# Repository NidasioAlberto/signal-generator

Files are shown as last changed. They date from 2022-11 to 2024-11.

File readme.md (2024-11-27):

# Signal Generator with an STM32

## Introduction

The main idea of this project is to develop a waveform generator instrument using an STM32 microcontroller and its built-in DAC. The project has 2 parts:
- **Software**: The application needs to showcase the STM32 capability to output
            waveforms  at sample rates of 100kHz or greater. The software has to include a
            peripheral driver to access the built in DAC using DMA.
- **Hardware**: The device has to to implement a waveform generator output stage
            circuitry that allows to extend the capabilities of the built in DAC.

To achieve this goals a custom board was designed and software drivers were developed for the DAC and DMA. The final product also includes a text interface where the user can setup an arbitrary waveform and the device parses the user input using Flex and Bison.

<div align="center">
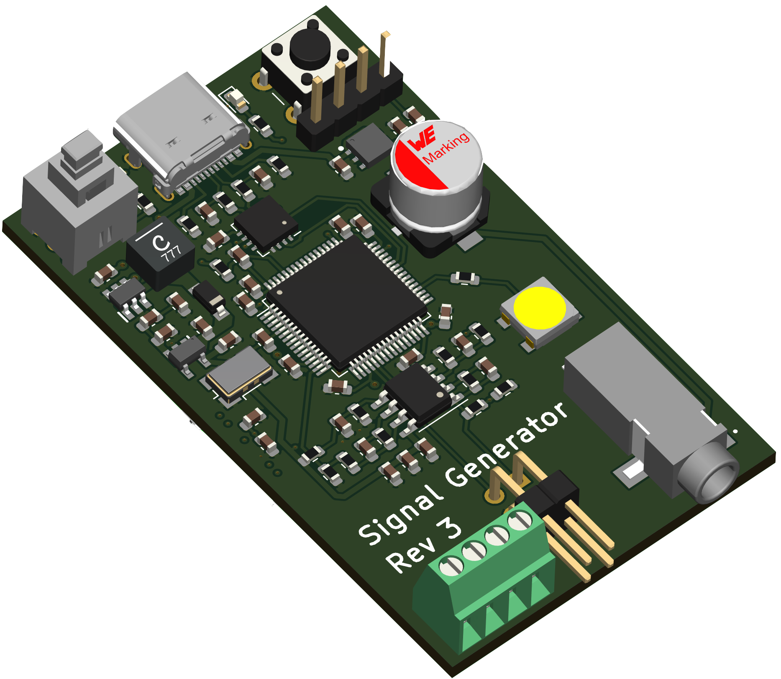
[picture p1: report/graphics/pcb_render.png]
Console Example
    
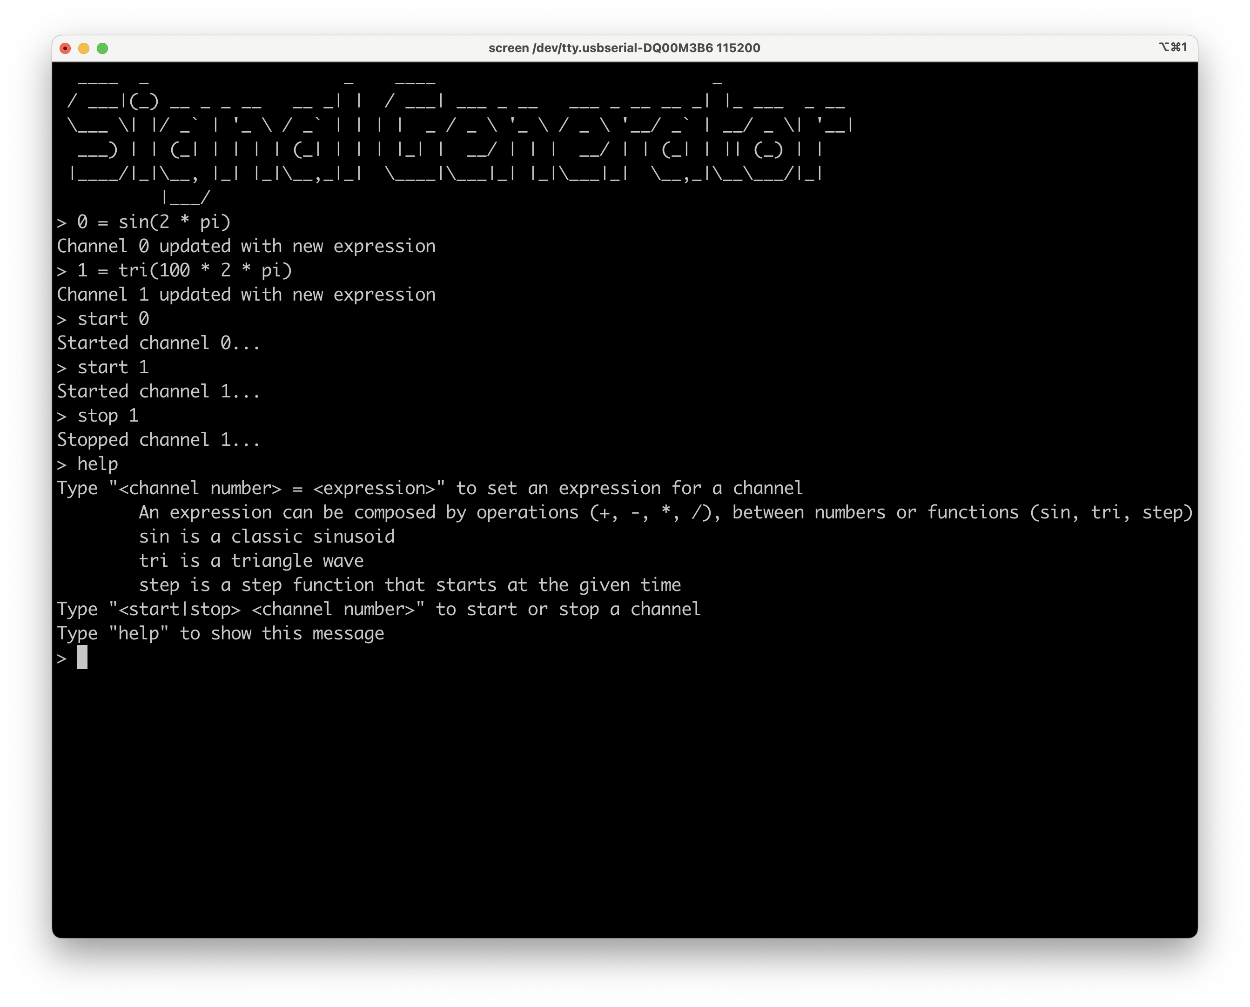
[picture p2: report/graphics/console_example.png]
PCB Render
    
</div>

## Analog Front End

The stm32 incorporates a Digital-to-Analog Converter (DAC) with an integrated output buffer. When enabled, the buffer allows the DAC to drive external loads directly. However, this comes at the cost of limited driving capability, especially when interfacing with capacitive loads. Disabling the buffer offers a pure analog output, but necessitates an external buffer or amplifier to drive any meaningful external load. The inherent impedance of the DAC's output pin can also cause distortions and constrain the signal's frequency, particularly when dealing with capacitive loads.

Integrating an external operational amplifier (op-amp) into the analog front-end offers multiple advantages:

- **Buffering DAC Output**: The op-amp serves as a buffer, isolating the DAC from the actual load. This setup minimizes the effects of the DAC output pin's impedance, enabling the DAC to operate in a near-ideal environment.
- **Voltage Scaling**: Configured in a non-inverting amplifier mode, the op-amp provides adjustable gain, facilitating flexible signal amplitude adjustments.

Given that the board is powered via USB, which typically provides 5V, there's a need to step up this voltage to achieve the 12V requirement for the analog front end:

- **Boost Converter**: The TLV61048 boost converter is employed to step up the USB's 5V to 13.12V.
- **Linear Voltage Regulator**: Following the boost converter, an LDO is used to convert the 13.12V from the boost converter to a stable 12V output. This stable 12V supply is crucial to ensure that the analog front-end, especially the operational amplifier, operates with consistency.

The opamp circuit also features a voltage divider to feedback the output signal to the STM32's ADC. This could allow the microcontroller to perform automatic calibration of the opamp gains.
Here's the provided LaTeX content converted into markdown:

## Microcontroller and digital domain

The STM32F205 is a low-end microcontroller with a 120MHz clock speed, 128KB of RAM, and the required peripherals needed by the project (DAC, DMA, and timers). It was used mainly because it was already stocked in the lab.

The board also features:
- An external 25MHz crystal oscillator to drive the microcontroller.
- A USB to UART bridge to allow the user to interact with the device via a serial terminal.
- An RGBW addressable led used for status indication.
- A header connector that exposes the SWD programming interface.
- Two buttons: one for reset and one for the BOOT0 pin.
- A microSD card slot to store files.

## Software architecture

The software powering the signal generator board is built upon the [Miosix operating system](https://github.com/NidasioAlberto/miosix-kernel) and features 2 main components:
- Drivers for the DAC and DMA peripherals.
- A parser built using Flex and Bison that allows interpreting the user input into arbitrary math functions used to generate the output waveform.

### Peripherals drivers

The STM32F205 microcontroller is equipped with a versatile Digital-to-Analog Converter (DAC) peripheral that offers 12-bit resolution and two separate channels, effectively incorporating two DACs. This dual-channel architecture permits simultaneous generation of two distinct analog outputs, allowing our custom board to feature two independent output channels.

The DAC's conversion process can be initiated through multiple methods. It can be triggered manually via software, which provides direct control over the conversion timing. Alternatively, for applications requiring precise and periodic analog outputs, external triggers can be employed. A common external trigger source is a timer, which can initiate DAC conversions at predetermined intervals, ensuring consistent waveform generation.

The STM32's DAC is also designed with the capability to generate DMA requests. Once the DAC is ready for new data, it can signal the DMA peripheral to fetch the next data sample. The DMA (Direct Memory Access) controller is a powerful tool designed to handle data transfers independently of the CPU's operation. This peripheral is characterized by sixteen independent streams, each of which can be paired with different peripherals, granting a wide range of configuration possibilities. By leveraging the DMA's rapid data transfer capabilities, the DAC can be persistently supplied with data while leaving the CPU time to generate new data samples or perform other tasks.

One of its standout features is the double buffering mode. This mode uses two memory pointers: while one buffer is actively engaged by the DMA stream, the other can be prepared by the CPU, ensuring uninterrupted data flow.

In the context of the signal generator project, the DMA plays a crucial role. Each DAC is set up to utilize an external trigger originating from a timer. With every trigger event, the DAC issues a DMA request for a new data sample. The DMA has been configured in double buffer mode. Alternatively, a single buffer mode combined with the half-transfer interrupt could have been adopted to achieve a similar result. This integration of the DAC with the DMA and a timer is what ultimately powers the project's ability to generate high-frequency waveforms even with a low-end microcontroller such as the STM32F205.

The developed drivers are C++ classes that abstract the peripherals and allow the programmer to easily configure and use them. In particular, the DMA driver is divided into two classes and one struct:
- **DMADriver**: A singleton that manages all DMA streams. When a piece of code needs a stream, it can request it to the DMADriver. If the stream is already in use, the DMADriver will pause the thread until the stream is available, otherwise, it will acquire the stream and return it to the caller.
- **DMATransaction**: A struct that holds all configuration parameters for a specific transfer. This includes source and destination addresses, data size, double buffer, interrupts, and so on.
- **DMAStream**: This class allows configuring the stream for a specific transaction, start and stop it, and easily handle interrupts. In particular, interrupts can be waited for with or without a timeout (thanks to the Miosix's timed wait feature) or registering a callback function that will be called when the interrupt occurs.

# Project outcomes

## Concrete outcomes

The project achieved two concrete outcomes:
- **Electronic board**: The board was designed and assembled successfully. It includes an analog front end that extends the capabilities of the STM32's built-in DAC and also includes features, such as the ADC feedback and micro SD, that allows further experimentation.
- **Software drivers**: Two software drivers were developed, one for the DAC and one for the DMA. These allow the use of the peripherals in a simple and efficient way.

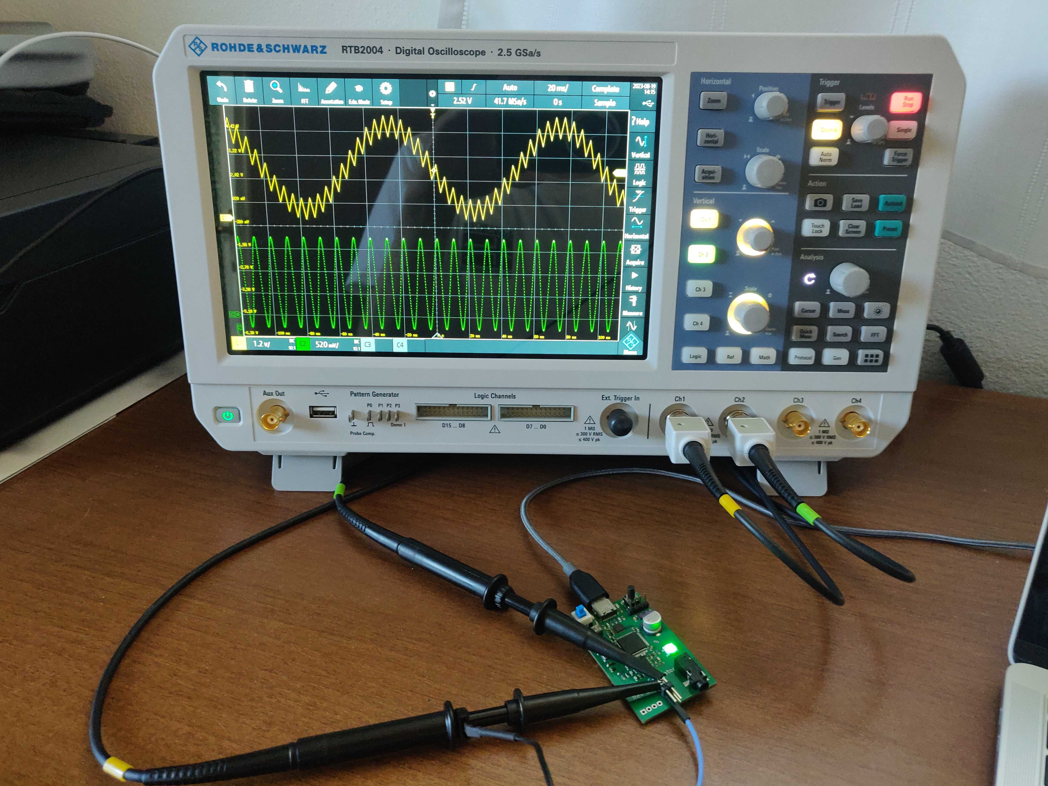
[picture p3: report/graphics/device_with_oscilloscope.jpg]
Signal Generator board hooked up to an oscilloscope


## Learning outcomes

Developing both the hardware and the software allowed me not only to learn about the STM32 microcontroller and its peripherals but also to learn about the whole process of designing and assembling a PCB.

Particular effort went into the design of the board itself, selecting and sourcing the components, and manually assembling the board. It was a challenge because, being my first time creating a complex PCB with a microcontroller, I was not well prepared. I had to learn about the different types of components, which were required for my design, and which not. Some special takeaways were the importance of reading carefully the components datasheet, finding application notes to understand similar projects, and learning how to design and order a PCB (with KiCad and JLCPCB).

The assembly of the board was the most exciting part because I got to see my design come to life. I procured the necessary soldering equipment (solder paste, a hot plate, a hot air gun, and a microscope) and I soldered the board first by distributing the solder paste with a stencil and then by heating the board with the hot plate for the top layer, and with the hot air gun for the bottom layer. I had to learn how to use the equipment and how to solder the different components.

The software side was instead more akin to my previous experiences. I had already worked with microcontrollers and already used the Miosix operating system. However, I had never worked with the DMA peripheral. The most challenging aspects were understanding how the peripherals work by reading the reference manual and also finding examples online which are hard to come by.

## Existing knowledge

The most useful knowledge that helped me in this project came from 3 sources:
- **Advanced Operating System**: In particular, the parts on concurrency, thread programming, and analysis of the features in the Miosix operating system.
- **Embedded Systems**: The course gave me a good understanding of the development process of a microcontroller-based system, both for the design aspects and for the production processes involved.
- **Skyward Experimental Rocketry**: Most of the experience I had prior to this academic year was my involvement in the Skyward Experimental Rocketry team. Previously I was involved in the design and development of the software for the rocket. This year I also had the responsibility of managing the production of the avionic system as a whole, including the electronic part. This gave me a good opportunity to work on another project and the luck of knowing lots of talented teammates.

## Problems encountered

The worst setback I faced was the board redesign. In the first version, I used an STM32F103 which is a cheaper microcontroller that has no built-in DAC! I realized this only after I had assembled the board and tried to use it. I had to adjust the schematic and the PCB in order to use the STM32F205 instead and reorder the board.

Once the board was ready I faced other problems during the development of the drivers but I managed to solve them without major issues. In this process, the debugger was particularly useful to understand what was going on.

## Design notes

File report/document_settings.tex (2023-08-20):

\usepackage[english]{babel}
\usepackage[utf8x]{inputenc}
\usepackage{amsmath}
\usepackage{graphicx}
\usepackage[colorinlistoftodos]{todonotes}
\usepackage{hyperref}
\usepackage[a4paper]{geometry}
\geometry{top=3cm,left=2cm,right=2cm,bottom=3cm}
\usepackage[scaled]{helvet}
\usepackage[T1]{fontenc}
\renewcommand\familydefault{\sfdefault}
\usepackage{caption}
\usepackage{subcaption}

\hypersetup{
    colorlinks=true,
    linkcolor=black,
    filecolor=blue,
    urlcolor=magenta,
    citecolor=black,
}

\setlength{\parindent}{0pt}

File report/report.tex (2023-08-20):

\documentclass{article}

\input{document_settings.tex}

\author{Alberto Nidasio}
\date{\today}
\title{Signal Generator with an STM32}

\begin{document}

\maketitle
\tableofcontents

% \let\clearpage\relaxs
\input{sections/1_project_data.tex}
\input{sections/2_project_description.tex}
\input{sections/3_project_outcomes.tex}
\input{sections/4_honor_pledges.tex}

\end{document}

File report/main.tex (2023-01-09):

\documentclass{article}

\input{document_settings.tex}

\author{Alberto Nidasio}
\date{\today}
\title{Signal Generator with an STM32}

\begin{document}

\maketitle
\tableofcontents

\include{sections/project_data.tex}
\include{sections/project_description.tex}
\include{sections/project_outcomes.tex}
\include{sections/honor_pledges.tex}

\end{document}

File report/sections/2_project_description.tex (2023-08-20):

\section{Project description}

\subsection{Introduction}

The main idea of this project is to develop a waveform generator instrument using an STM32 microcontroller and its built-in DAC. The project has 2 parts:
\begin{itemize}
      \item \textbf{Software}: The application needs to showcase the STM32 capability to output
            waveforms  at sample rates of 100kHz or greater. The software has to include a
            peripheral driver to access the built in DAC using DMA.
      \item \textbf{Hardware}: The device has to to implement a waveform generator output stage
            circuitry that allows to extend the capabilities of the built in DAC.
\end{itemize}

To achieve this goals a custom board was designed and software drivers were developed for the DAC and DMA.

The final product also includes a text interface where the user can setup an arbitrary waveform and the device parses the user input using Flex and Bison.

\begin{figure}[h]
      \captionsetup[subfigure]{labelformat=empty}
      \centering
      \begin{subfigure}[b]{0.45\textwidth}
            \centering
            
            \caption{PCB}
      \end{subfigure}
      \hfill
      \begin{subfigure}[b]{0.50\textwidth}
            \centering
            
            \caption{Text interface}
      \end{subfigure}
\end{figure}

\subsection{Design of the Printed Circuit Board}

The goal I set out to achieve is create a stand-alone PCB with builtin micro controller and front-end circuit that blends the stm32's built-in features and external components, to produce a high-frequency arbitrary waveforms with a 12V peak without external power supplies.

\subsubsection{Analog Front End}

The stm32 incorporates a Digital-to-Analog Converter (DAC) with an integrated output buffer. When enabled, the buffer allows the DAC to drive external loads directly. However, this comes at the cost of limited driving capability, especially when interfacing with capacitive loads. Disabling the buffer offers a pure analog output, but necessitates an external buffer or amplifier to drive any meaningful external load. The inherent impedance of the DAC's output pin can also cause distortions and constrain the signal's frequency, particularly when dealing with capacitive loads.

\bigbreak

Integrating an external operational amplifier (op-amp) into the analog front-end offers multiple advantages:
\begin{itemize}
      \item  \textbf{Buffering DAC Output}: The op-amp serves as a buffer, isolating the DAC from the actual load. This setup minimizes the effects of the DAC output pin's impedance, enabling the DAC to operate in a near-ideal environment.
      \item \textbf{Voltage Scaling}: Configured in a non-inverting amplifier mode, the op-amp provides adjustable gain, facilitating flexible signal amplitude adjustments.
\end{itemize}

Given that the board is powered via USB, which typically provides 5V, there's a need to step up this voltage to achieve the 12V requirement for the analog front end:
\begin{itemize}
      \item \textbf{Boost Converter}: The TLV61048 boost converter is employed to step up the USB's 5V to 13.12V.
      \item \textbf{Linear Voltage Regulator}: Following the boost converter, an LDO is used to convert the 13.12V from the boost converter to a stable 12V output. This stable 12V supply is crucial to ensure that the analog front-end, especially the operational amplifier, operates with consistency.
\end{itemize}

The opamp circuit also features a voltage divider to feedback the output signal to the STM32's ADC. This could allow the microcontroller to perform automatic calibration of the opamp gains.

\begin{figure}[h]
      \captionsetup[subfigure]{labelformat=empty}
      \centering
      \begin{subfigure}[b]{0.4\textwidth}
            \centering
            
            \caption{Front end}
      \end{subfigure}
      \hfill
      \begin{subfigure}[b]{0.59\textwidth}
            \centering
            
            \caption{Power stage}
      \end{subfigure}
\end{figure}

\subsubsection{Microcontroller and digital domain}

The STM32F205 is a low-end microcontroller with a 120MHz clock speed, 128KB of RAM and the required peripherals needed by the project (DAC, DMA and timers). It was used mainly because it was already stocked in the lab.

The board also features:
\begin{itemize}
      \item An external 25MHz crystal oscillator to drive the microcontroller.
      \item A USB to UART bridge to allow the user to interact with the device via a serial terminal.
      \item An RGBW addressable led used for status indication.
      \item An header connector that exposes the SWD programming interface.
      \item Two buttons: one for reset and one for the BOOT0 pin.
      \item A microsd card slot to store files.
\end{itemize}

\subsection{Software architecture}

The software powering the signal generator board is built upon the \href{https://github.com/NidasioAlberto/miosix-kernel}{Miosix operating system} and features 2 main components:
\begin{itemize}
      \item Drivers for the DAC and DMA peripherals.
      \item A parser built using Flex and Bison that allows to interpret the user input into arbitrary math functions used to generate the output waveform.
\end{itemize}

\subsubsection{Peripherals drivers}

The STM32F205 microcontroller is equipped with a versatile Digital-to-Analog Converter (DAC) peripheral that offers 12-bit resolution and two separate channels, effectively incorporating two DACs. This dual-channel architecture permits simultaneous generation of two distinct analog outputs, allowing our custom board to feature two independent output channels.

\bigbreak

The DAC's conversion process can be initiated through multiple methods. It can be triggered manually via software, which provides direct control over the conversion timing. Alternatively, for applications requiring precise and periodic analog outputs, external triggers can be employed. A common external trigger source is a timer, which can initiate DAC conversions at predetermined intervals, ensuring consistent waveform generation.

\bigbreak

The STM32's DAC is designed also with the capability to generate DMA requests. Once the DAC is ready for new data, it can signal the DMA peripheral to fetch the next data sample. The DMA (Direct Memory Access) controller is a powerful tool designed to handle data transfers independently of the CPU's operation. This peripheral is characterized by sixteen independent streams each of which can be paired with different peripherals, granting a wide range of configuration possibilities. By leveraging the DMA's rapid data transfer capabilities, the DAC can be persistently supplied with data while leaving the CPU time to generate new data samples or perform other tasks.

One of its standout features is the double buffering mode. This mode uses two memory pointers: while one buffer is actively engaged by the DMA stream, the other can be prepared by the CPU, ensuring uninterrupted data flow.

\bigbreak

In the context of the signal generator project, the DMA plays a crucial role. Each DAC is set up to utilize an external trigger originating from a timer. With every trigger event, the DAC issues a DMA request for a new data sample. The DMA has been configured in double buffer mode. Alternatively, a single buffer mode combined with the half-transfer interrupt could have been adopted to achieve a similar result. This integration of the DAC with the DMA and a timer is what ultimately powers the project's ability to generate high-frequency waveforms even with a low end microcontroller such as the STM32F205.

\bigbreak

The developed drivers are C++ classes that abstract the peripherals and allows the programmer to easily configure and use them. In particular the DMA driver is divided into two classes and one struct:
\begin{itemize}
      \item \textbf{DMADriver}: A singleton that manages all DMA streams. When a piece of code needs a stream, it can request it to the DMADriver. If the stream is already in use, the DMADriver will pause the thread until the stream is available, otherwise it will acquire the stream and return it to the caller.
      \item \textbf{DMATransaction}: A struct that holds all configuration parameters for a specific transfer. This includes source and destination addresses, data size, double buffer, interrupts and so on.
      \item \textbf{DMAStream}: This class allows to configure the stream with for a specific transaction, start and stop it and easily handle interrupts. In particular interrupts can be waited with or without a timeout (thank to the Miosix's timed wait feature) or registering a callback function that will be called when the interrupt occurs.
\end{itemize}

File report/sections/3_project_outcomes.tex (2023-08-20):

\section{Project outcomes}

\subsection{Concrete outcomes}

The project achieved two concrete outcomes:
\begin{itemize}
      \item \textbf{Electronic board}: The board was designed and assembled successfully. It includes an analog front end that extends the capabilities of the STM32's built in DAC and also includes features, such as the adc feedback and micro sd, that allows further experimentation.
      \item \textbf{Software drivers}: Two software drivers were developed, one for the DAC and one for the DMA. These allows to use the peripherals in a simple and efficient way.
\end{itemize}

\begin{figure}[h]
      \captionsetup[figure]{labelformat=empty}
      \centering
      
      \caption{Signal Generator board hooked up to an oscilloscope}
\end{figure}

\subsection{Learning outcomes}

Developing both the hardware and the software allowed me not only to learn about the stm32 microcontroller and its peripherals, but also to learn about the whole process of designing and assembling a PCB.

\bigbreak

Particular effort went into the design of the board itself, selecting and sourcing the components and manually assembling the board. It was a challenge because, being my first time creating a complex PCB with a microcontroller, I was not well prepared. I had to learn about the different types of components, which were required for my design and which not. Some special takeaways were the importance of reading carefully the components datasheet, finding application notes to understand similar projects and learning how to design and order a PCB (with KiCad and JLCPCB).

\bigbreak

The assembly of the board was the most exciting part because I got to see my design come to life. I procured the necessary soldering equipment (solder paste, a hot plate, a hot air gun and a microscope) and I soldered the board first by distributing the solder paste with a stencil and then by heating the board with the hot plate for the top layer, and with the hot air gun for the bottom layer. I had to learn how to use the equipment and how to solder the different components.

\bigbreak

The software side was instead more akin to my previous experiences. I had already worked with microcontrollers and already used the Miosix operating system. However, I had never worked with the DMA peripheral. The most challenging aspects were to understand how the peripherals works by reading the reference manual and also find examples online which are hard to come by.

\subsection{Existing knowledge}

The most useful knowledge that helped me in this project came from 3 sources:
\begin{itemize}
      \item \textbf{Advanced Operating System}: In particular the parts on concurrency, thread programming and analysis of the features in the Miosix operating system.
      \item \textbf{Embedded Systems}: The course gave me a good understanding of the development process of a microcontroller based system, both for the design aspects and for the production processes involved.
      \item \textbf{Skyward Experimental Rocketry}: Most of the experience I had prior to this academic year was my involvement in the Skyward Experimental Rocketry team. Previously I was involved in the design and development of the software for the rocket. This year I also had the responsibility of managing the production of the avionic system as a whole, including the electronic part. This gave me a good opportunity to work on another project and the luck of knowing lots of talented teammates.
\end{itemize}

\subsection{Problems encountered}

The worst setback I faced was the board redesign. In the first version I used an STM32F103 which is a cheaper microcontroller that has not built in DAC! I realized this only after I had assembled the board and tried to use it. I had to adjust the schematic and the PCB in order to use the STM32F205 instead and reorder the board.

Once the board was ready I faced other problems during the development of the drivers but I managed to solve them without major issues. In this process the debugger was particularly useful to understand what was going on.

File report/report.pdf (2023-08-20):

## Signal Generator with an STM32

Alberto Nidasio

August 20, 2023

## Contents

1 Project data | 1
2 Project description | 1
3 Project outcomes | 4
4 Honor Pledge | 6

## 1 Project data

- Project supervisor: Daniele Cattaneo (daniele.cattaneo@polimi.it)
- Project author:
Last and first name | Person code | Email address
Nidasio Alberto | 10665344 | alberto.nidasio@mail.polimi.com
- The project available on GitHub in this repository. (https://github.com/NidasioAlberto/signal-generator) It contains:
Folder | Content
code | The application code
code/libs/miosix-kernel | A submodule linking to a Miosix Kernel fork (https://github.com/NidasioAlberto/miosix-kernel)
docs | Documents used for reference during development
pcb | KiCad design files of the PCB
report | LaTeX files of this report

## 2 Project description

### 2.1 Introduction

The main idea of this project is to develop a waveform generator instrument using an STM32 microcontroller and its built-in DAC. The project has 2 parts:

- Software: The application needs to showcase the STM32 capability to output waveforms at sample rates of 100kHz or greater. The software has to include a peripheral driver to access the built in DAC using DMA.
- Hardware: The device has to to implement a waveform generator output stage circuitry that allows to extend the capabilities of the built in DAC.

To achieve this goals a custom board was designed and software drivers were developed for the DAC and DMA. The final product also includes a text interface where the user can setup an arbitrary waveform and the device parses the user input using Flex and Bison.

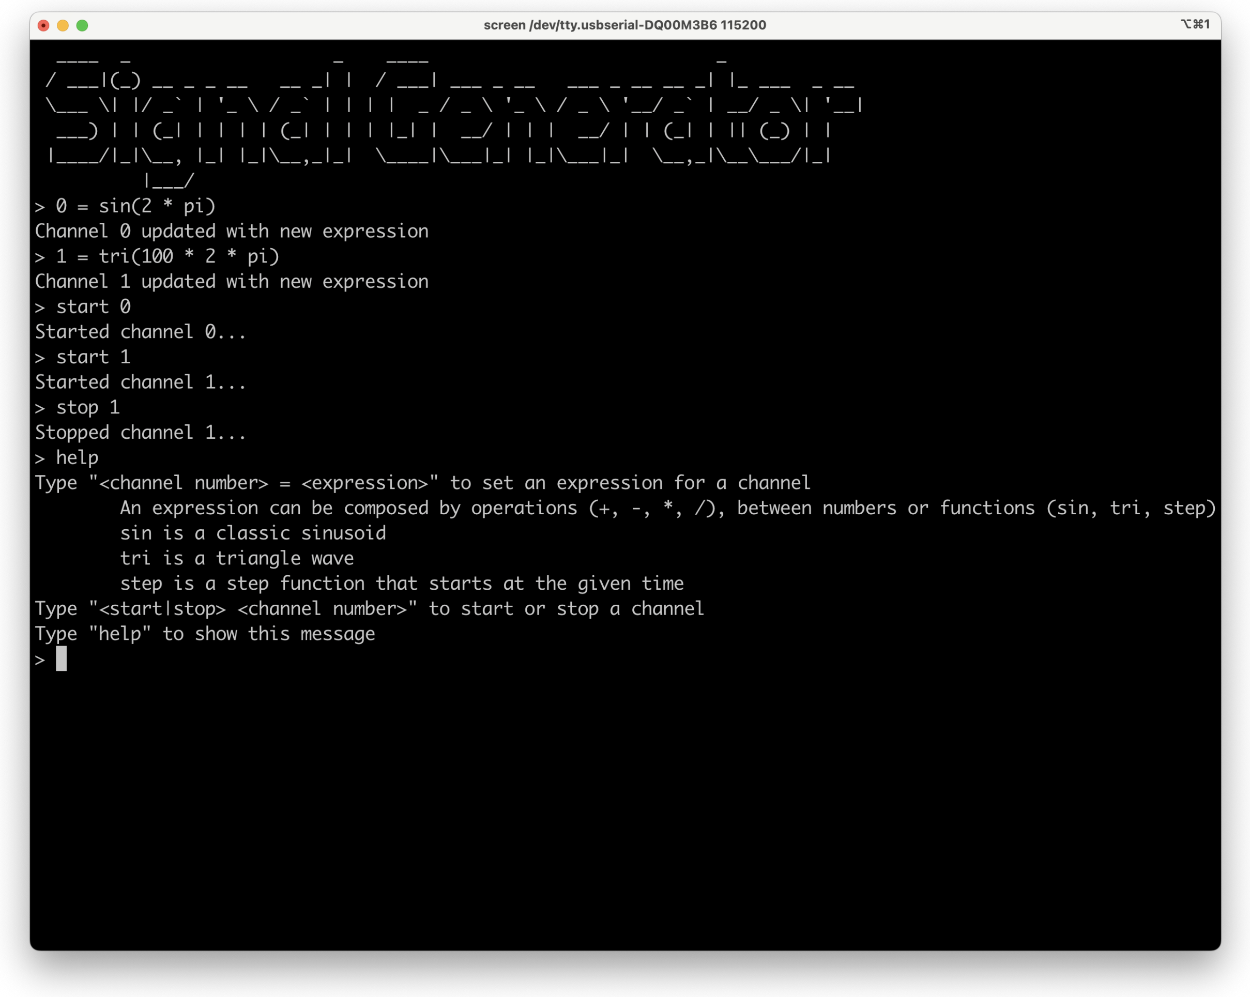
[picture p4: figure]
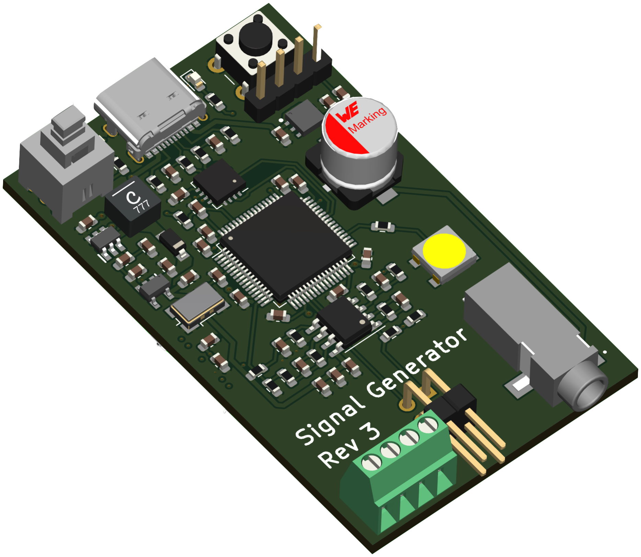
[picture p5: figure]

PCB | Text interface

### 2.2 Design of the Printed Circuit Board

The goal I set out to achieve is create a stand-alone PCB with builtin micro controller and front-end circuit that blends the stm32’s built-in features and external components, to produce a high-frequency arbitrary waveforms with a 12V peak without external power supplies.

### 2.2.1 Analog Front End

The stm32 incorporates a Digital-to-Analog Converter (DAC) with an integrated output buffer. When enabled, the buffer allows the DAC to drive external loads directly. However, this comes at the cost of limited driving capability, especially when interfacing with capacitive loads. Disabling the buffer offers a pure analog output, but necessitates an external buffer or amplifier to drive any meaningful external load. The inherent impedance of the DAC’s output pin can also cause distortions and constrain the signal’s frequency, particularly when dealing with capacitive loads.

Integrating an external operational amplifier (op-amp) into the analog front-end offers multiple advantages:

- Buffering DAC Output: The op-amp serves as a buffer, isolating the DAC from the actual load. This setup minimizes the effects of the DAC output pin’s impedance, enabling the DAC to operate in a near-ideal environment.
- Voltage Scaling: Configured in a non-inverting amplifier mode, the op-amp provides adjustable gain, facilitating flexible signal amplitude adjustments.

Given that the board is powered via USB, which typically provides 5V, there’s a need to step up this voltage to achieve the 12V requirement for the analog front end:

- Boost Converter: The TLV61048 boost converter is employed to step up the USB’s 5V to 13.12V.

- Linear Voltage Regulator: Following the boost converter, an LDO is used to convert the 13.12V from the boost converter to a stable 12V output. This stable 12V supply is crucial to ensure that the analog front-end, especially the operational amplifier, operates with consistency.

The opamp circuit also features a voltage divider to feedback the output signal to the STM32’s ADC. This could allow the microcontroller to perform automatic calibration of the opamp gains.

R11

## 46.4k C⁹ 0.5p

R7
4.75k

R8
1.33k

GND

C7
100n
GND | GND

R13
240k

1 - 2

+ 3

U2A
Opamp_Dual

R14
91k

+12VA

CH2_IN

CH2_OUT

CH2_FEEDBACK

R7
4.75k

R8
1.33k

C7
100n
GND | GND

R14
91k

+12VA

GND

Front end

C29
1u

GND

C30
1u

IN 1

GND 2

EN 3 | OUT 5

U7
LDK320AM120R

R19
1.54M

R20
100k

GND

GND

GND

D4
D_Zener

PWR_FLAG

C28
10u

L1
4.7u

SW 1
GND 2
FB 3 EN 4

VIN 5
FREQ 6

U6
TLV61048

GND

GND

C25
1u

12V

5V | 13.12V

C25
1u

GND

C28
10u

GND

R20 GND

100k

U7
LDK320AM120R
IN 1

GND 2

EN 3 | OUT 5

C30
1u

Power stage

### 2.2.2 Microcontroller and digital domain

The STM32F205 is a low-end microcontroller with a 120MHz clock speed, 128KB of RAM and the required peripherals needed by the project (DAC, DMA and timers). It was used mainly because it was already stocked in the lab.
The board also features:
- An external 25MHz crystal oscillator to drive the microcontroller.
- A USB to UART bridge to allow the user to interact with the device via a serial terminal.
- An RGBW addressable led used for status indication.
- An header connector that exposes the SWD programming interface.
- Two buttons: one for reset and one for the BOOT0 pin.
- A microsd card slot to store files.

### 2.3 Software architecture

The software powering the signal generator board is built upon the Miosix operating system (https://github.com/NidasioAlberto/miosix-kernel) and features 2 main components:

- Drivers for the DAC and DMA peripherals.
- A parser built using Flex and Bison that allows to interpret the user input into arbitrary math functions used to generate the output waveform.

### 2.3.1 Peripherals drivers

The STM32F205 microcontroller is equipped with a versatile Digital-to-Analog Converter (DAC) peripheral that offers 12-bit resolution and two separate channels, effectively incorporating two DACs. This dual-channel architecture permits simultaneous generation of two distinct analog outputs, allowing our custom board to feature two independent output channels.

The DAC’s conversion process can be initiated through multiple methods. It can be triggered manually via software, which provides direct control over the conversion timing. Alternatively, for applications requiring precise and periodic analog outputs, external triggers can be employed. A common external trigger source is a timer, which can initiate DAC conversions at predetermined intervals, ensuring consistent waveform generation.

The STM32’s DAC is designed also with the capability to generate DMA requests. Once the DAC is ready for new data, it can signal the DMA peripheral to fetch the next data sample. The DMA (Direct Memory Access) controller is a powerful tool designed to handle data transfers independently of the CPU’s operation. This peripheral is characterized by sixteen independent streams each of which can be paired with different peripherals, granting a wide range of configuration possibilities. By leveraging the DMA’s rapid data transfer capabilities, the DAC can be persistently supplied with data while leaving the CPU time to generate new data samples or perform other tasks. One of its standout features is the double buffering mode. This mode uses two memory pointers: while one buffer is actively engaged by the DMA stream, the other can be prepared by the CPU, ensuring uninterrupted data flow.

In the context of the signal generator project, the DMA plays a crucial role. Each DAC is set up to utilize an external trigger originating from a timer. With every trigger event, the DAC issues a DMA request for a new data sample. The DMA has been configured in double buffer mode. Alternatively, a single buffer mode combined with the half-transfer interrupt could have been adopted to achieve a similar result. This integration of the DAC with the DMA and a timer is what ultimately powers the project’s ability to generate high-frequency waveforms even with a low end microcontroller such as the STM32F205.

The developed drivers are C++ classes that abstract the peripherals and allows the programmer to easily configure and use them. In particular the DMA driver is divided into two classes and one struct:

- DMADriver: A singleton that manages all DMA streams. When a piece of code needs a stream, it can request it to the DMADriver. If the stream is already in use, the DMADriver will pause the thread until the stream is available, otherwise it will acquire the stream and return it to the caller.
- DMATransaction: A struct that holds all configuration parameters for a specific transfer. This includes source and destination addresses, data size, double buffer, interrupts and so on.
- DMAStream: This class allows to configure the stream with for a specific transaction, start and stop it and easily handle interrupts. In particular interrupts can be waited with or without a timeout (thank to the Miosix’s timed wait feature) or registering a callback function that will be called when the interrupt occurs.

## 3 Project outcomes

### 3.1 Concrete outcomes

The project achieved two concrete outcomes:

- Electronic board: The board was designed and assembled successfully. It includes an analog front end that extends the capabilities of the STM32’s built in DAC and also includes features, such as the adc feedback and micro sd, that allows further experimentation.
- Software drivers: Two software drivers were developed, one for the DAC and one for the DMA. These allows to use the peripherals in a simple and efficient way.

### 3.2 Learning outcomes

Developing both the hardware and the software allowed me not only to learn about the stm32 microcontroller and its peripherals, but also to learn about the whole process of designing and assembling a PCB.

Particular effort went into the design of the board itself, selecting and sourcing the components and manually assembling the board. It was a challenge because, being my first time creating a complex PCB with a microcontroller, I was not well prepared. I had to learn about the different types of components, which were required for my design and which not. Some special takeaways were the importance of reading carefully the components datasheet, finding application notes to understand similar projects and learning how to design and order a PCB (with KiCad and JLCPCB).


Figure 3: Signal Generator board hooked up to an oscilloscope

The assembly of the board was the most exciting part because I got to see my design come to life. I procured the necessary soldering equipment (solder paste, a hot plate, a hot air gun and a microscope) and I soldered the board first by distributing the solder paste with a stencil and then by heating the board with the hot plate for the top layer, and with the hot air gun for the bottom layer. I had to learn how to use the equipment and how to solder the different components.

The software side was instead more akin to my previous experiences. I had already worked with microcontrollers and already used the Miosix operating system. However, I had never worked with the DMA peripheral. The most challenging aspects were to understand how the peripherals works by reading the reference manual and also find examples online which are hard to come by.

### 3.3 Existing knowledge

The most useful knowledge that helped me in this project came from 3 sources:

- Advanced Operating System: In particular the parts on concurrency, thread programming and analysis of the features in the Miosix operating system.
- Embedded Systems: The course gave me a good understanding of the development process of a microcontroller based system, both for the design aspects and for the production processes involved.
- Skyward Experimental Rocketry: Most of the experience I had prior to this academic year was my involvement in the Skyward Experimental Rocketry team. Previously I was involved in the design and development of the software for the rocket. This year I also had the responsibility of managing the production of the avionic system as a whole, including the electronic part. This gave me a good opportunity to work on another project and the luck of knowing lots of talented teammates.

### 3.4 Problems encountered

The worst setback I faced was the board redesign. In the first version I used an STM32F103 which is a cheaper microcontroller that has not built in DAC! I realized this only after I had assembled the board and tried to use it. I had to adjust the schematic and the PCB in order to use the STM32F205 instead and reorder the board.
Once the board was ready I faced other problems during the development of the drivers but I managed to solve them without major issues. In this process the debugger was particularly useful to understand what was going on.

## 4 Honor Pledge

I pledge that this work was fully and wholly completed within the criteria established for academic integrity by Politecnico di Milano (Code of Ethics and Conduct) and represents my original production, unless otherwise cited.
I also understand that this project, if successfully graded, will fulfill part B requirement of the Advanced Operating System course and that it will be considered valid up until the AOS exam of Sept. 2023.

Students’ signature

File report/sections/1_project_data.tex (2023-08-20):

\section{Project data}

\begin{itemize}
    \item Project supervisor: Daniele Cattaneo (daniele.cattaneo@polimi.it)
    \item Project author:
          \begin{center}
              \begin{tabular}{lll}
                  Last and first name & Person code & Email address                   \\
                  \hline
                  Nidasio Alberto     & 10665344    & alberto.nidasio@mail.polimi.com \\
              \end{tabular}
          \end{center}
    \item The project available on GitHub in \href{https://github.com/NidasioAlberto/signal-generator}{this repository}. It contains:
          \begin{center}
              \begin{tabular}{ll}
                  Folder                           & Content                                                                                             \\
                  \hline
                  \texttt{code}                    & The application code                                                                                \\
                  \texttt{code/libs/miosix-kernel} & A submodule linking to a \href{https://github.com/NidasioAlberto/miosix-kernel}{Miosix Kernel fork} \\
                  \texttt{docs}                    & Documents used for reference during development                                                     \\
                  \texttt{pcb}                     & KiCad design files of the PCB                                                                       \\
                  \texttt{report}                  & LaTeX files of this report
              \end{tabular}
          \end{center}
\end{itemize}

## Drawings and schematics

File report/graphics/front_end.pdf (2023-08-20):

# 46.4k C⁹ 0.5p

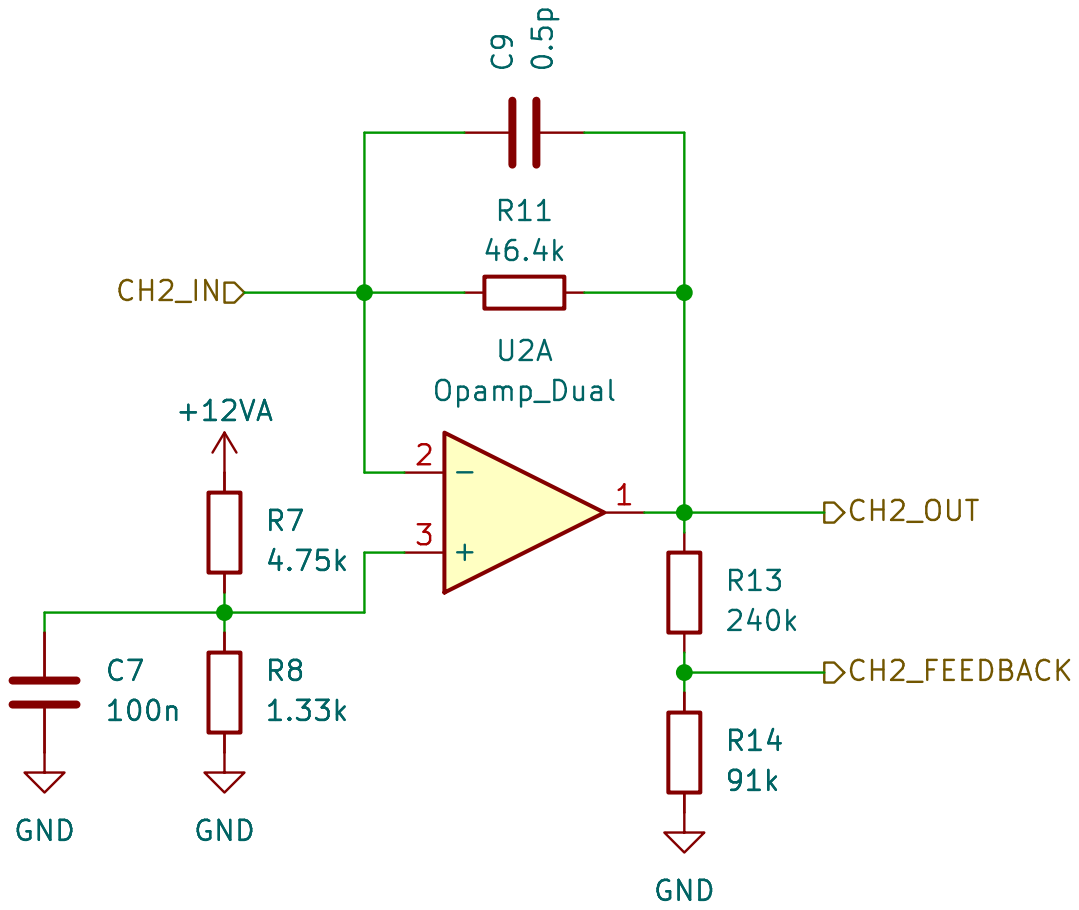
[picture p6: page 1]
GND; U2A Opamp_Dual; CH2_OUT; CH2_FEEDBACK

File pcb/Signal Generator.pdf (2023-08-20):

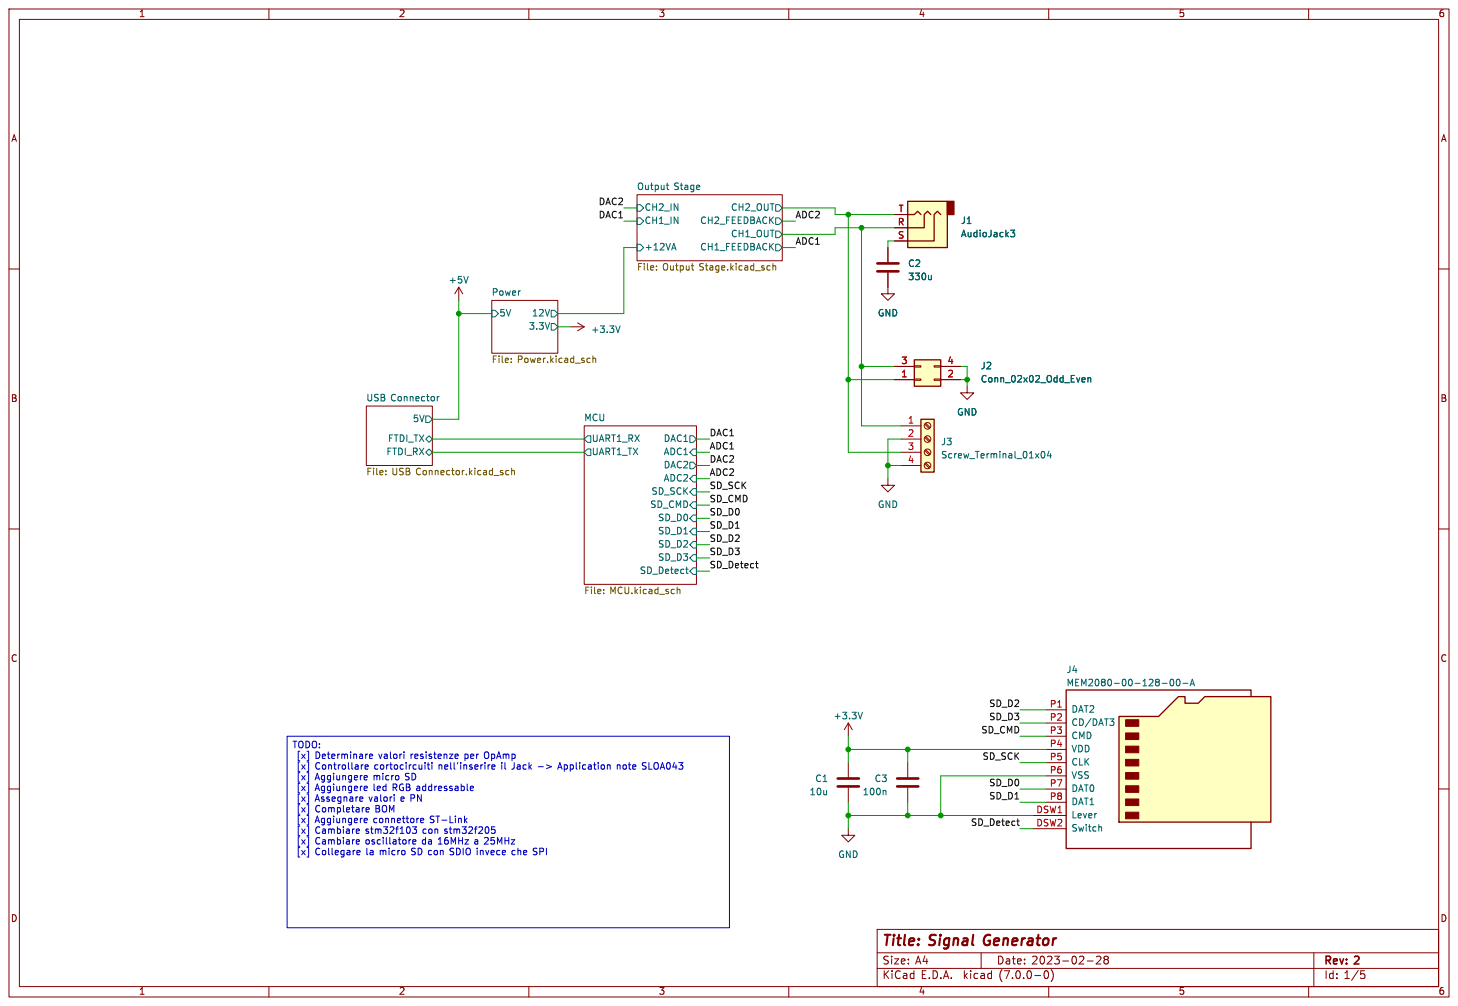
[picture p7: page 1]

+12VA Output Stage File: Output Stage.kicad_sch

FTDI_RX USB Connector File: USB Connector.kicad_sch

[x] Aggiungere micro SD
[x] Aggiungere led RGB addressable
[x] Assegnare valori e PN
[x] Collegare la micro SD con SDIO invece che SPI

Id: 1/5 Title: Signal Generator

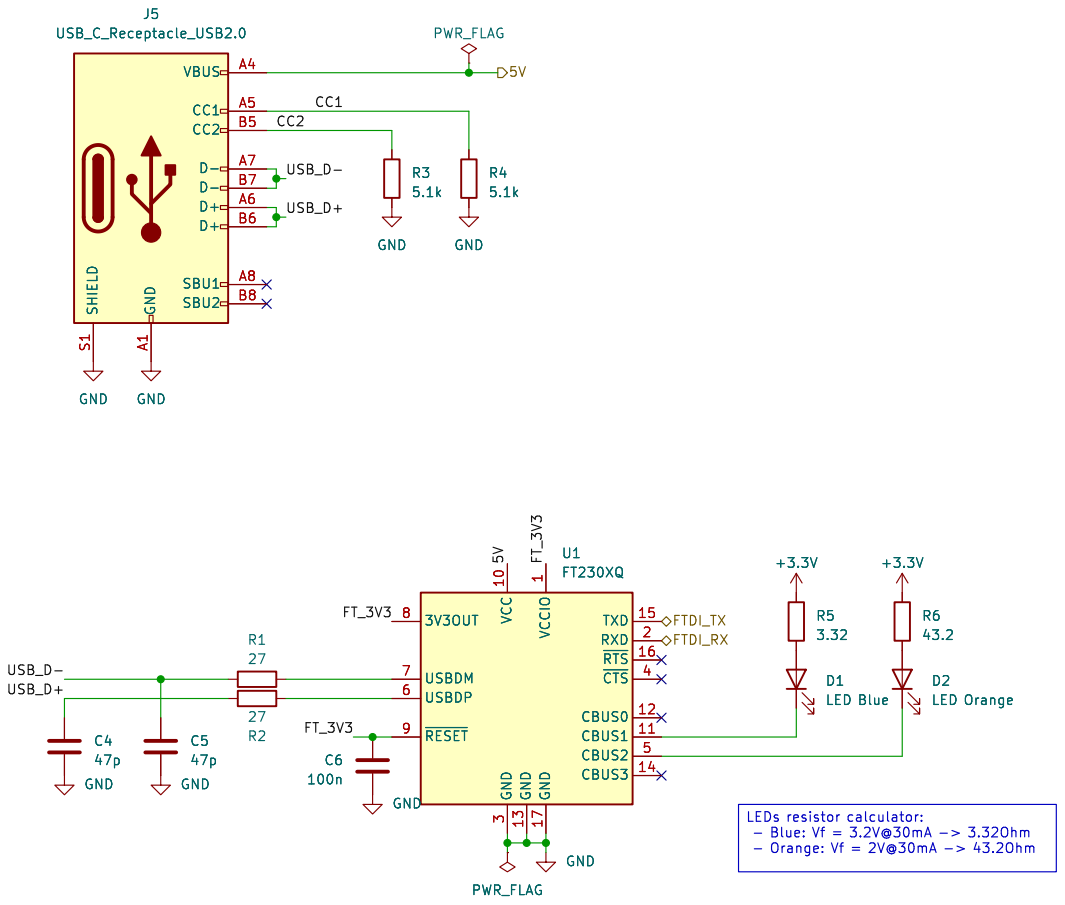
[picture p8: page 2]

1 VCC 10 CBUS1 11 CBUS0 12 GND 13 CBUS3 14 TXD 15 ~{RTS}16 GND 17 RXD 2 GND

Id: 2/5 Title: USB Connector R6

LEDs resistor calculator: - Blue: Vf = 3.2V@30mA -> 3.32Ohm

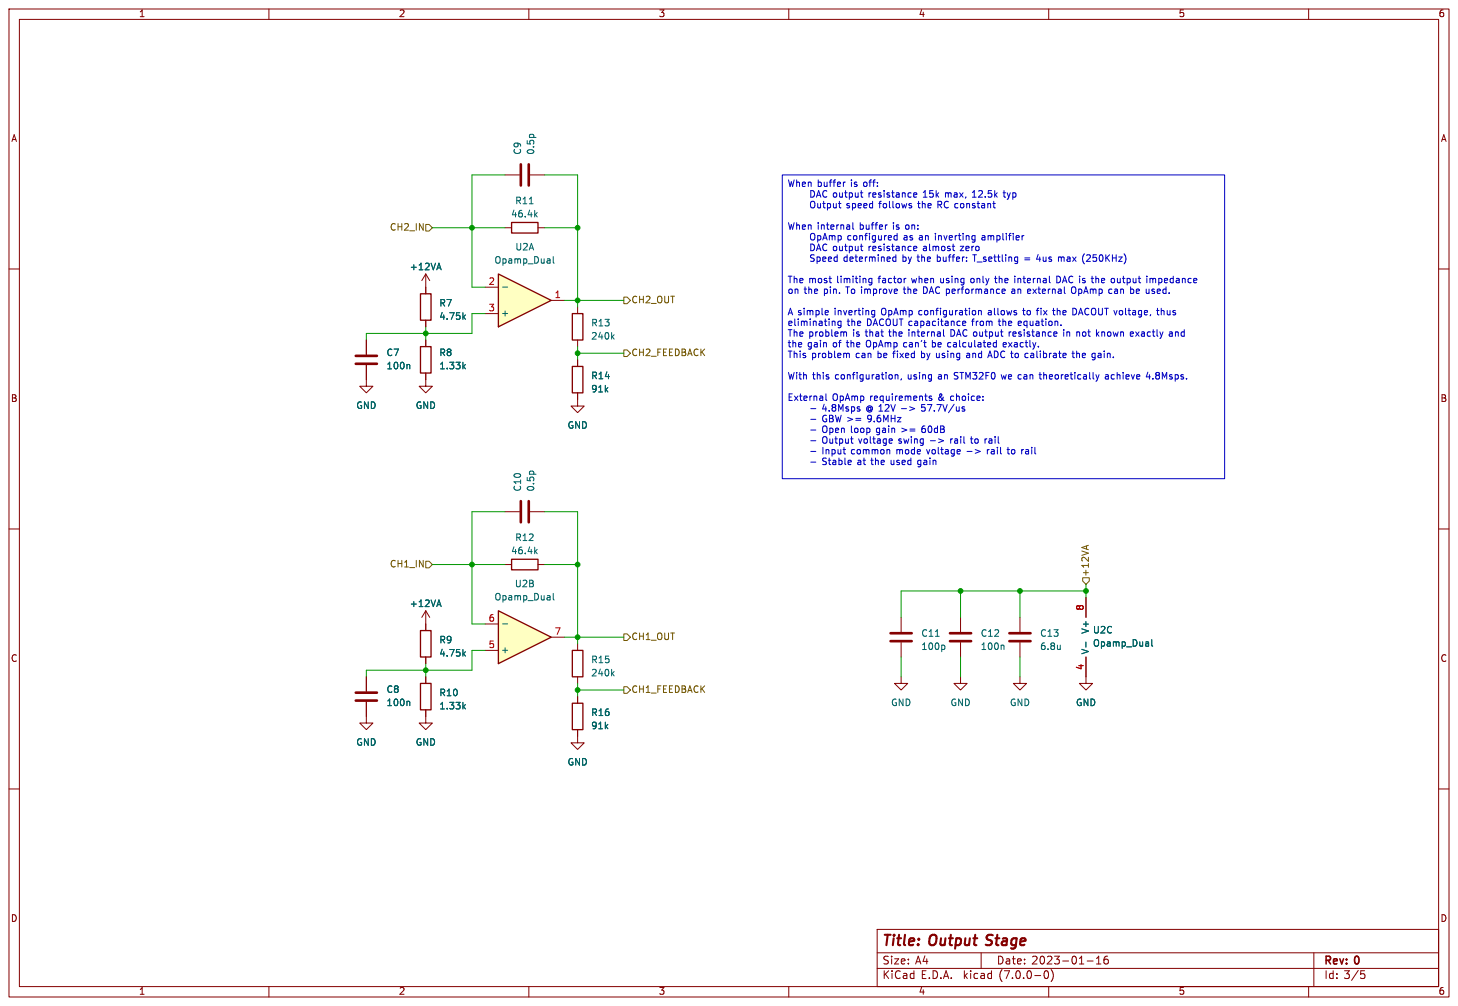
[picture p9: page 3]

Id: 3/5 Title: Output Stage

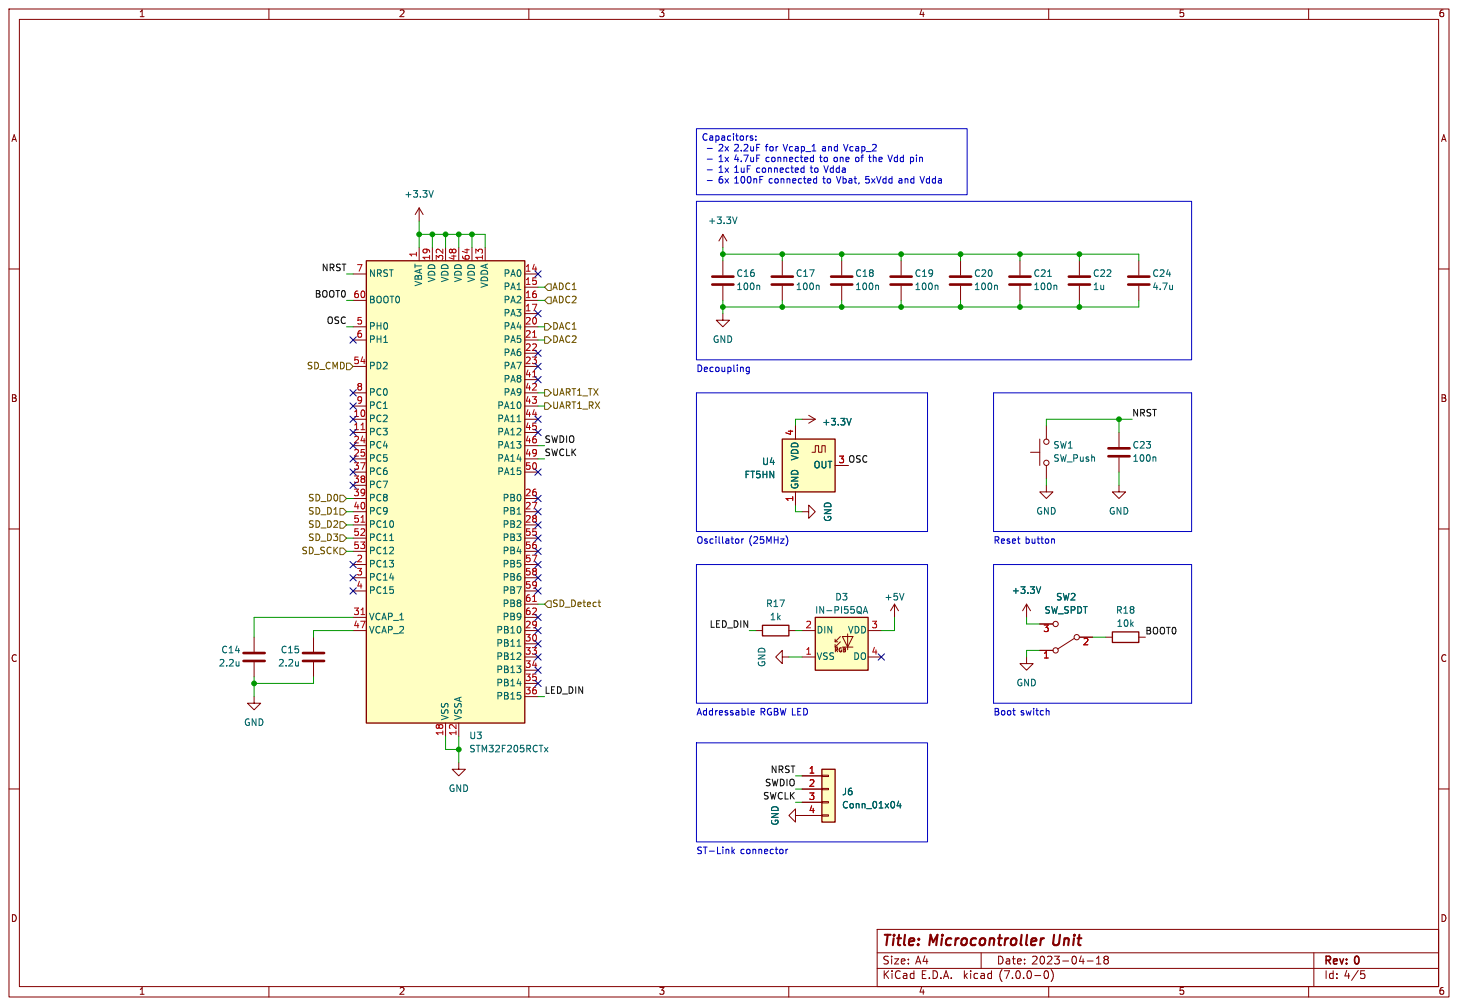
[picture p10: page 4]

Capacitors: - 2x 2.2uF for Vcap_1 and Vcap_2 - 1x 4.7uF connected to one of the Vdd pin - 1x 1uF connected to Vdda - 6x 100nF connected to Vbat, 5xVdd and Vdda +3.3V

Reset button Boot switch

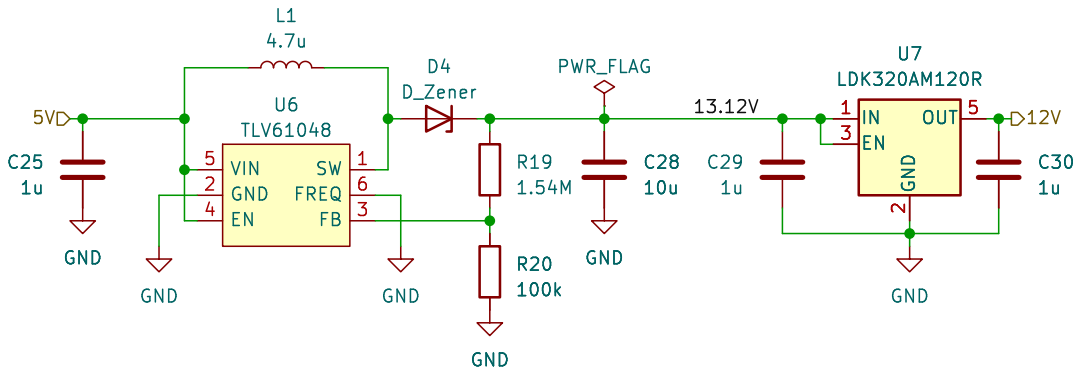
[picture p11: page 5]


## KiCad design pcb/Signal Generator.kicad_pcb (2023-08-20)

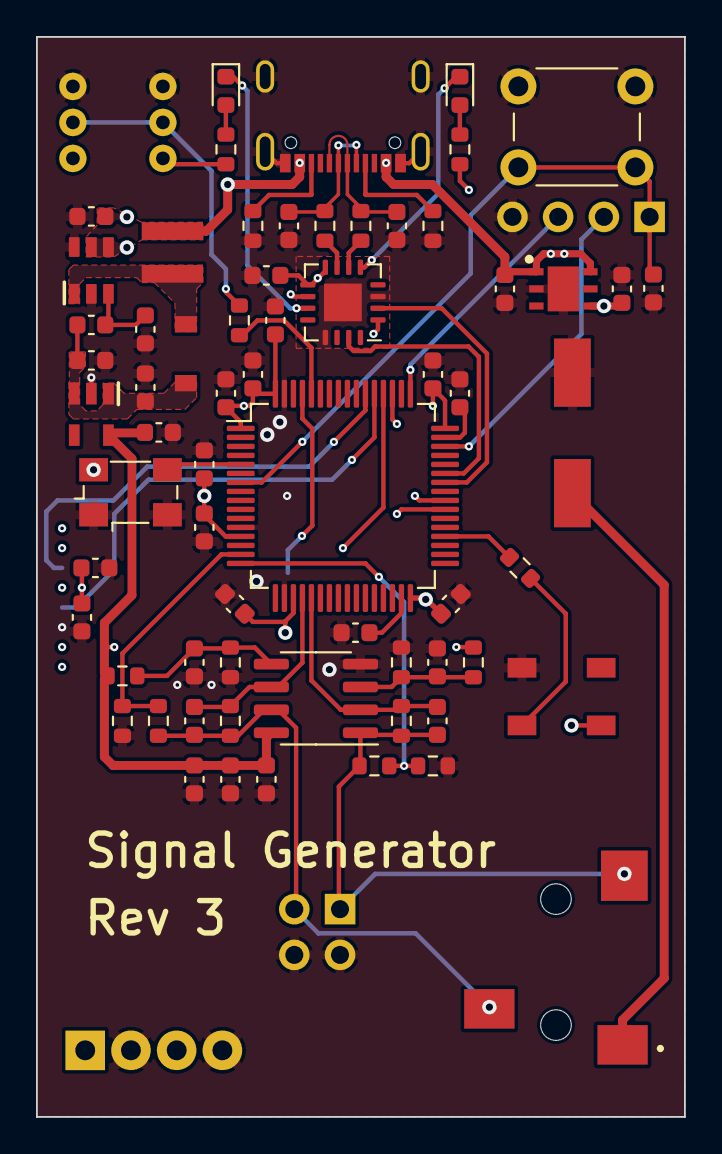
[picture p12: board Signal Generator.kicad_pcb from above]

Board: 4 copper layers, 36.0 x 60.0 mm, 70 parts (1 on the bottom side), 46 nets.

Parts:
C1, C28: 10u; C_0603_1608Metric
C2: 330u; WCAP-PSHP
C3, C6, C7, C8, C12, C16, C17, C18, C19, C20, C21, C23: 100n; C_0603_1608Metric
C4, C5: 47p; C_0603_1608Metric
C9, C10: 0.5p; C_0603_1608Metric
C11: 100p; C_0603_1608Metric
C13: 6.8u; C_0603_1608Metric
C14, C15: 2.2u; C_0603_1608Metric
C22, C25, C26, C27, C29, C30: 1u; C_0603_1608Metric
C24: 4.7u; C_0603_1608Metric
D1: LED Blue; LED_0603_1608Metric
D2: LED Orange; LED_0603_1608Metric
D3: IN-PI55QA
D4: D_Zener; BZT52C10-TP
J1: AudioJack3; SJ-3523-SMT-TR
J2: Conn_02x02_Odd_Even; PinHeader_2x02_P2.54mm_Horizontal
J3: Screw_Terminal_01x04; TerminalBlock_Phoenix_MPT-0,5-4-2.54_1x04_P2.54mm_Horizontal
J4: MEM2080-00-128-00-A
J5: USB_C_Receptacle_USB2.0; USB4105-GF-A
J6: Conn_01x04; PinHeader_1x04_P2.54mm_Vertical
L1: 4.7u; XAL4030
R1, R2: 27; R_0603_1608Metric
R3, R4: 5.1k; R_0603_1608Metric
R5: 3.32; R_0603_1608Metric
R6: 43.2; R_0603_1608Metric
R7, R9: 4.75k; R_0603_1608Metric
R8, R10: 1.33k; R_0603_1608Metric
R11, R12: 46.4k; R_0603_1608Metric
R13, R15: 240k; R_0603_1608Metric
R14, R16: 91k; R_0603_1608Metric
R17: 1k; R_0603_1608Metric
R18: 10k; R_0603_1608Metric
R19: 1.54M; C_0603_1608Metric
R20: 100k; C_0603_1608Metric
SW1: SW_Push; SW_PUSH_6mm_H5mm
SW2: SW_SPDT; Push Button Switch 7x7mm
U1: FT230XQ; QFN-16-1EP_4x4mm_P0.65mm_EP2.1x2.1mm
U2: Opamp_Dual; SOIC-8_3.9x4.9mm_P1.27mm
U3: STM32F205RCTx; LQFP-64_10x10mm_P0.5mm
U4: FT5HN; Oscillator_SMD_Fox_FT5H_5.0x3.2mm
U5: LD39050PU33R
U6: TLV61048
U7: LDK320AM120R

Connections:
+3.3V: C1.1, C3.1, C16.1, C17.1, C18.1, C19.1, C20.1, C21.1, C22.1, C24.1, C27.1, J4.P4 (VDD), R5.1, R6.2, SW2.3 (C), U3.1 (VBAT), U3.13 (VDDA), U3.19 (VDD), U3.32 (VDD), U3.48 (VDD), U3.64 (VDD), U4.4 (VDD), U5.4 (VOUT)
+5V: C25.1, C26.1, D3.3 (VDD), J5.A4 (VBUS), J5.A9 (VBUS), J5.B4 (VBUS), J5.B9 (VBUS), L1.1, U1.10 (VCC), U5.1 (EN), U5.6 (VIN), U6.4 (EN), U6.5 (VIN)
+12VA: C11.1, C12.1, C13.1, C30.1, R7.2, R9.2, U2.8 (V+), U7.5 (OUT)
/ADC1: R15.2, R16.1, U3.15 (PA1)
/ADC2: R13.2, R14.1, U3.16 (PA2)
/DAC1: C10.1, R12.1, U2.6 (-), U3.20 (PA4)
/DAC2: C9.1, R11.1, U2.2 (-), U3.21 (PA5)
/MCU/BOOT0: R18.1, U3.60 (BOOT0)
/MCU/LED_DIN: R17.1, U3.36 (PB15)
/MCU/NRST: C23.1, J6.1, SW1.2, U3.7 (NRST)
/MCU/OSC: U3.5 (PH0), U4.3 (OUT)
/MCU/SWCLK: J6.3, U3.49 (PA14)
/MCU/SWDIO: J6.2, U3.46 (PA13)
/MCU/UART1_RX: U1.15 (TXD), U3.43 (PA10)
/MCU/UART1_TX: U1.2 (RXD), U3.42 (PA9)
/Output Stage/CH1_OUT: C10.2, J1.R, J2.3, J3.1, R12.2, R15.1, U2.7
/Output Stage/CH2_OUT: C9.2, J1.T, J2.1, J3.3, R11.2, R13.1, U2.1
/Power/13.12V: C28.1, C29.1, D4.1 (K), R19.1, U7.1 (IN), U7.3 (EN)
/SD_CMD: J4.P3 (CMD), U3.54 (PD2)
/SD_D0: J4.P7 (DAT0), U3.39 (PC8)
/SD_D1: J4.P8 (DAT1), U3.40 (PC9)
/SD_D2: J4.P1 (DAT2), U3.51 (PC10)
/SD_D3: J4.P2 (CD/DAT3), U3.52 (PC11)
/SD_Detect: J4.DSW2 (Switch), U3.61 (PB8)
/SD_SCK: J4.P5 (CLK), U3.53 (PC12)
/USB Connector/CC1: J5.A5 (CC1), R4.2
/USB Connector/CC2: J5.B5 (CC2), R3.1
/USB Connector/FT_3V3: C6.1, U1.1 (VCCIO), U1.8 (3V3OUT), U1.9 (~RESET)
/USB Connector/USB_D+: C4.1, J5.A6 (D+), J5.B6 (D+), R2.2
/USB Connector/USB_D-: C5.1, J5.A7 (D-), J5.B7 (D-), R1.1
GND: C1.2, C2.2, C3.2, C4.2, C5.2, C6.2, C7.2, C8.2, C11.2, C12.2, C13.2, C14.2, C15.2, C16.2, C17.2, C18.2, C19.2, C20.2, C21.2, C22.2, C23.2, C24.2, C25.2, C26.2, C27.2, C28.2, C29.2, C30.2, D3.1 (VSS), J2.2, J2.4, J3.2, J3.4, J4.DSW1 (Lever), J4.P6 (VSS), J5.A1 (GND), J5.A12 (GND), J5.B1 (GND), J5.B12 (GND), J5.S1 (SHIELD), J6.4, R3.2, R4.1, R8.1, R10.1, R14.2, R16.2, R20.2, SW1.1, SW2.1 (A), U1.3 (GND), U1.13 (GND), U1.17 (GND), U2.4 (V-), U3.12 (VSSA), U3.18 (VSS), U3.63 (VSS), U4.1 (GND), U4.2 (GND), U5.2 (GND), U5.7 (PAD), U6.2 (GND), U6.6 (FREQ), U7.2 (GND)
unnamed: C2.1, J1.S
unnamed: D1.2 (A), R5.2
unnamed: D1.1 (K), U1.11 (CBUS1)
unnamed: D2.2 (A), R6.1
unnamed: D2.1 (K), U1.5 (CBUS2)
unnamed: D3.2 (DIN), R17.2
unnamed: D4.2 (A), L1.2, U6.1 (SW)
unnamed: R18.2, SW2.2 (B)
unnamed: R1.2, U1.7 (USBDM)
unnamed: R2.1, U1.6 (USBDP)
unnamed: C7.1, R7.1, R8.2, U2.3 (+)
unnamed: C8.1, R9.1, R10.2, U2.5 (+)
unnamed: C14.1, U3.31 (VCAP_1)
unnamed: C15.1, U3.47 (VCAP_2)
unnamed: R19.2, R20.1, U6.3 (FB)

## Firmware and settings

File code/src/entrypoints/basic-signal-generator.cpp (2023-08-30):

/***************************************************************************
 *   Copyright (C) 2023 by Alberto Nidasio                                 *
 *                                                                         *
 *   This program is free software; you can redistribute it and/or modify  *
 *   it under the terms of the GNU General Public License as published by  *
 *   the Free Software Foundation; either version 2 of the License, or     *
 *   (at your option) any later version.                                   *
 *                                                                         *
 *   This program is distributed in the hope that it will be useful,       *
 *   but WITHOUT ANY WARRANTY; without even the implied warranty of        *
 *   MERCHANTABILITY or FITNESS FOR A PARTICULAR PURPOSE.  See the         *
 *   GNU General Public License for more details.                          *
 *                                                                         *
 *   As a special exception, if other files instantiate templates or use   *
 *   macros or inline functions from this file, or you compile this file   *
 *   and link it with other works to produce a work based on this file,    *
 *   this file does not by itself cause the resulting work to be covered   *
 *   by the GNU General Public License. However the source code for this   *
 *   file must still be made available in accordance with the GNU General  *
 *   Public License. This exception does not invalidate any other reasons  *
 *   why a work based on this file might be covered by the GNU General     *
 *   Public License.                                                       *
 *                                                                         *
 *   You should have received a copy of the GNU General Public License     *
 *   along with this program; if not, see <http://www.gnu.org/licenses/>   *
 ***************************************************************************/

#include <drivers/DAC/DAC.h>
#include <drivers/DMA/DMA.h>
#include <drivers/timer/GeneralPurposeTimer.h>
#include <miosix.h>
#include <util/util.h>

#include <cmath>
#include <thread>

#define PI 3.14159265358979f

using namespace miosix;

DACDriver dac;
DMAStream& stream5 =
    DMADriver::instance().acquireStream(DMAStreamId::DMA1_Str5);
GP32bitTimer tim2(TIM2);

static constexpr size_t SIGNAL_ARRAY_SIZE = 10e3;
static uint16_t buffer[SIGNAL_ARRAY_SIZE] = {0};

static constexpr int TIMER_FREQUENCY = 5e6;

static int counter1 = 0;
static int counter2 = 0;

void loadBuffer() {
    for (size_t i = 0; i < SIGNAL_ARRAY_SIZE; i++) {
        float time = (1.0 / TIMER_FREQUENCY) * i;
        float val = 5 * sin(100e3 * 2 * PI * time) + 5.5;

        // Convert to DAC values
        uint16_t rawVal = (1 - val / 12) * 4095;
        buffer[i] = rawVal < 4096 ? rawVal : 4095;

        // Debug
        // printf("[%.9f] %f -> %d\n", time, val, rawVal);
    }
}

int main() {
    CPUProfiler p;

    // Prepare the buffers
    loadBuffer();

    // Setup DAC
    {
        dac.enableChannel(DACDriver::Channel::CH1);
        dac.disableBuffer(DACDriver::Channel::CH1);
        dac.enableDMA(DACDriver::Channel::CH1);
        dac.enableTrigger(DACDriver::Channel::CH1,
                          DACDriver::TriggerSource::TIM2_TRGO);
    }

    // Setup DMA
    {
        DMATransaction trn{
            .channel = DMATransaction::Channel::CHANNEL7,
            .direction = DMATransaction::Direction::MEM_TO_PER,
            .priority = DMATransaction::Priority::HIGH,
            .srcSize = DMATransaction::DataSize::BITS_16,
            .dstSize = DMATransaction::DataSize::BITS_16,
            .srcAddress = buffer,
            .dstAddress = &(DAC->DHR12R1),
            .numberOfDataItems = SIGNAL_ARRAY_SIZE,
            .srcIncrement = true,
            .circularMode = true,
        };
        stream5.setup(trn);
        stream5.enable();
    }

    // Setup TIM2
    {
        tim2.setMasterMode(TimerUtils::MasterMode::UPDATE);
        tim2.setFrequency(2 * TIMER_FREQUENCY);
        tim2.setAutoReloadRegister(1);
        tim2.enable();
    }

    printf("Started\n");

    while (true) {
        Thread::sleep(1000);
    };
}

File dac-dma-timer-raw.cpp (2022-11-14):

#include <drivers/dac/dac.h>
#include <math.h>
#include <miosix.h>

#define PI 3.14159265358979f

using namespace std;
using namespace miosix;

// Serial pins: PA9 PA10
typedef Gpio<GPIOA_BASE, 4> ch1;

constexpr size_t UPDATE_FREQ = 1e6;

constexpr size_t SIGNAL_ARRAY_SIZE = 100;
uint32_t signal_data[SIGNAL_ARRAY_SIZE] = {0};

void loadWave() {
    float step = 2 * PI / SIGNAL_ARRAY_SIZE;

    for (size_t i = 0; i < SIGNAL_ARRAY_SIZE; i++)
        signal_data[i] =
            static_cast<uint32_t>(sinf(step * i) * 2047.5 + 2047.5);
}

int main() {
    loadWave();

    // DAC
    {
        ch1::mode(Mode::INPUT_ANALOG);

        // Enable the DAC clock
        RCC->APB1ENR |= RCC_APB1ENR_DACEN;

        // Enable DAC ch1
        DAC->CR |= DAC_CR_EN1;

        // Enable DMA on DAC ch1
        DAC->CR |= DAC_CR_DMAEN1;

        // Select TIM6 as trigger by writing 000 in TSEL1
        DAC->CR &= ~DAC_CR_TSEL1;

        // Enable DAC ch1 trigger
        DAC->CR |= DAC_CR_TEN1;
    }

    // DMA
    {
        // Enable the DMA clock
        RCC->AHBENR |= RCC_AHBENR_DMA1EN;

        // Configure the peripheral data register address
        DMA1_Channel3->CPAR |= reinterpret_cast<uint32_t>(&(DAC->DHR12R1));

        // Configure the memory address
        DMA1_Channel3->CMAR |= reinterpret_cast<uint32_t>(signal_data);

        // Configure the number of DMA transfer to perform
        DMA1_Channel3->CNDTR = SIGNAL_ARRAY_SIZE;

        // Enable memory increment
        DMA1_Channel3->CCR |= DMA_CCR_MINC;

        // Memory size 32bit
        DMA1_Channel3->CCR |= DMA_CCR_MSIZE_1;

        // Peripheral size 32 bit
        DMA1_Channel3->CCR |= DMA_CCR_PSIZE_1;

        // Set transfer form memory to peripheral
        DMA1_Channel3->CCR |= DMA_CCR_DIR;

        // Enable circular mode
        DMA1_Channel3->CCR |= DMA_CCR_CIRC;

        // Enable the DMA channel 3
        DMA1_Channel3->CCR |= DMA_CCR_EN;
    }

    // TIM6
    {
        // Enable the TIM6 clock
        RCC->APB1ENR |= RCC_APB1ENR_TIM6EN;

        // Set as TRGO source the UEV
        TIM6->CR2 |= TIM_CR2_MMS_1;

        // Set the prescaler
        TIM6->PSC = 4;

        // Set the auto reload register
        TIM6->ARR = 1;

        // Enable the timer
        TIM6->CR1 |= TIM_CR1_CEN;
    }

    while (true)
        ;
}

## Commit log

2022-11-08 Tested DAC with DMA and timer
2022-11-14 Tested DAC and DMA with new drivers
2022-11-23 Tested the new DMA driver
2022-11-25 First attempt at adding support for the stm32f769ni discovery
2022-12-19 Created basic KiCad project with an stm32f103
    [Signal Generator.kicad_pcb, Signal Generator.kicad_sch, TG2520SMN.step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]
2023-01-09 Updated pcb
    [LDLN030G33R.step, Signal Generator.kicad_sch, TS972IYQT.step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]
2023-01-11 Updated schematic with almost final front end
    [Signal Generator.kicad_sch, USB Plugs.kicad_sch]
2023-01-12 Updated pcb library
    [LD39050PU33R.step, LDLN030G33R.step, SJ-3523-SMT-TR.step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]
2023-01-12 Added connectors and organized schematic in multiple sheets
    [MCU.kicad_sch, Output Stage.kicad_sch, Power.kicad_sch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]
2023-01-13 Completed schematic oranization and components connection
    [LDK320AM120R.step, MCU.kicad_sch, Output Stage.kicad_sch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]
2023-01-15 Added micro SD and RGB led to schematic. Also added components part numbers
    [BZT52C10-TP.step, IN-PI55QA.stp, MCU.kicad_sch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]
2023-01-16 Completed schematic and tried some simulations
    [MCU.kicad_sch, Output Stage Simulation.kicad_pcb, Output Stage Simulation.kicad_sch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]
2023-01-16 Added ST-Link connector to schematic
    [501568-0607.step, MCU.kicad_sch, Signal Generator.kicad_pcb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]
2023-01-16 Added blocking capacitor to headphones jack
    [MCU.kicad_sch, Output Stage.kicad_sch, Power.kicad_sch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]
2023-01-16 Updated some footprints
    [Signal Generator.kicad_pcb, Signal Generator.kicad_sch, TL2230.STEP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]
2023-01-28 Completed PCB and prepared production files
    [Output Stage.kicad_sch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]
2023-02-28 Updated PCB to correct some connection errors
    [MCU.kicad_sch, Output Stage.kicad_sch, Power.kicad_sch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]
2023-04-11 Fixed FTDI connection to the stm32
    [MCU.kicad_sch, Output Stage.kicad_sch, Power.kicad_sch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]
2023-04-18 Switch to stm32f205
    [MCU.kicad_sch, Output Stage.kicad_sch, Power.kicad_sch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]
2023-05-05 Prepared PCB rev 3
    [MCU.kicad_sch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]
2023-05-05 Ported SPI driver from Boardcore
2023-05-05 Ported timer drivers from Boardcore
2023-05-05 Added DMA driver
2023-05-05 Added DAC driver
2023-05-19 Added support for custom target stm32f205rc_signal_generator
2023-05-23 Added ADC driver
2023-06-19 Tested DMA double buffering to generate a continuous wave
2023-06-19 Tested SPI with DMA and RGB led
2023-06-20 Added interrupts flags management to DMA driver
2023-06-21 Added interrupt handling to DMA driver
2023-06-21 Updated dac with dma test
2023-06-24 Updated footprint of IN-PI55QA led
    [IN-PI55QA.step]
2023-06-24 Moved pcb files in pcb folder
    [Output Stage Simulation.kicad_pcb, Output Stage Simulation.kicad_sch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]
2023-06-24 Fixed timers trigger sources for stm32f205
2023-06-24 Added Color struct to RGB led
2023-07-07 Updated pbc library paths
    [Signal Generator.kicad_pcb]
2023-08-14 Updated ClockUtils and TimerUtils with support for f7 micros
2023-08-14 Updated ADC driver with support for regular sequence trigger
2023-08-14 Added HUE clor type to the RGB led
2023-08-15 Added CPU command to print CPU usage
2023-08-17 Implemented fixed point library
    [Generator.cpp]
2023-08-20 Prepared report and readme page
    [Signal Generator.kicad_pcb]
2023-08-22 Fixed DMA driver and added getCurrentBufferNumber function
    [dac-dma-timer.cpp]
2023-08-30 Updated ChannelCtrlData struct and moved wave generation into threads
2023-08-30 Added checks for multiple starts and stops and fixed channel 1 thread
    [Generator.cpp]
2023-08-30 Prepared basic example for generating a wave with DAC, DMA and timer
